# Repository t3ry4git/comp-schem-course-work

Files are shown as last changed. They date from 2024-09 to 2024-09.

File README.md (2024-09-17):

# Курсова робота з дисципліни "Комп'ютерна схемотехніка"

## Загальне завдання

Розробити обчислювальну систему з мікропрограмним управлінням (за варiантом).

## Варіант №23

1. Ємнiсть оперативноi пам'ятi (ОЗП) - 32К(надо 8 штуки в ряду, 1 ряд);
2. Елементна база ОЗП - К541РУ2(1Кх4, кол. А - 10);
3. Ємнiсть постiйного запам'ятовувального пристрою (ПЗП) - 16К(надо 4 штуки в ряду, 2 ряда);
4. Елементна база ПЗП - К555РЕ4(2Кх8, кол. А - 11);
5. Розряднiсть основноi пам'ятi (ОЗП i ПЗП) та процесора - 32;
6. Елементна база блока обробки даних - К1804ВС1;
7. Наявнiсть схеми прискореного переносу: п - передбачається.
8. Елементна база ФАМ - К1804ВУ4;
9. Елементна база мiкропрограмної пам'ятi - К541РТ2;
10. Кiлькiсть зовнiшнiх пристроїв - 16;
11. Спосiб з'єднання мiкросхем прiоритетних векторних переривань - послідовний;
12. Елементна база контролера ПДП -  К1804ВУ6;
13. Обов'язковий тип даних: 3 - char;
14. Команда для детальної розробки: 2 - дiлення цілих двійкових чисел зі знаком (співмножники та результат - у доповняльному коді), - цілочисельне ділення: ділене, дільник, частка (зі знаком), остача (без знаку).
15. Принципова схема: 1 - БПП + БМУ.

## Оцінювання 
Робота: 80

Захист: відсутній

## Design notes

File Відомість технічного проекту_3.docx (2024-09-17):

Фор-мат | | Зона | | Поз. | Позначення | | | Найменування | | | | Кільк. | Прим.
| | | | | | | | Документація загальна
| | | | | | | | Новорозроблена
А4 | | | | | ІАЛЦ.467400.003 ПЗ | | | Обчислювальна система | | | | 39
| | | | | | | | з мікропрограмним
| | | | | | | | управлінням.
| | | | | | | | Пояснювальна записка
А1 | | | | | ІАЛЦ.467400.004 Е1 | | | Обчислювальна система | | | | 1
| | | | | | | | з мікропрограмним
| | | | | | | | управлінням.
| | | | | | | | Схема електрична
| | | | | | | | структурна
А2 | | | | | ІАЛЦ.467400.005 Е2 | | | Основна пам’ять. Схема | | | | 1
| | | | | | | | електрична
| | | | | | | | функціональна
А1 | | | | | ІАЛЦ.467400.006 E3 | | | БПП та БМУ. Схема | | | | 1
| | | | | | | | електрична принципова
А4 | | | | | ІАЛЦ.467400.007 ПЕ | | | БПП та БМУ. | | | | 1
| | | | | | | | Перелік елементів
| | | | | | | ІАЛЦ.467400.002 ТП
Зм. | Арк | | № докум | | Підпис | Дата
Розроб. | | | Терентьєв І.Д. | | | | Обчислювальна система з мікропрограмним управлінням. Відомість технічного проекту | | Літ. | | | Арк. | | Арк-ів
Перевір. | | | Клятченко Я.М. | | | | | | К | - | - | 1 | | 1
| | | | | | | | | КПІ ім. Ігоря Сікорського, ФПМ гр. КВ – 11
Н. контр.
Затв. | | | Клятченко Я.М.

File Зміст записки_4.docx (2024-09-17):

##### ЗМІСТ

ПЕРЕЛІК УМОВНИХ СКОРОЧЕНЬ 2

ВСТУП 3

РОЗДІЛ 1. Структура обчислювальної системи з мікропрограмним

управлінням 8

РОЗДІЛ 2. Основна пам’ять обчислювальної системи 22

РОЗДІЛ 3. Особливості побудови блока мікропрограмного управління та

блока пріоритетних переривань 24

РОЗДІЛ 4. Формати даних 26

РОЗДІЛ 5. Формати команд 27

РОЗДІЛ 6. Команди для детальної розробки 34

СПИСОК ВИКОРИСТАНИХ ДЖЕРЕЛ 39

ДОДАТКИ
| | | | | ІАЛЦ.467400.003 ПЗ
Зм. | Арк | № докум | Підпис | Дата
Розроб. | | Терентьєв І.Д. | | | Обчислювальна система з мікропрограмним управлінням. Пояснювальна записка | Літ. | | | Арк. | Арк-ів
Перев. | | Клятченко Я.М. | | | | К | - | - | 1 | 45
| | | | | | КПІ ім. Ігоря Сікорського, ФПМ, гр. КВ – 11
Н. контр.
Затв. | | Клятченко Я.М.

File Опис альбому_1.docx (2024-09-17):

Фор-мат | | Зона | | Поз. | Позначення | | | Найменування | | | | Кільк. | Прим.
| | | | | | | | Документація загальна
| | | | | | | | Новорозроблена
А4 | | | | | ІАЛЦ.467400.001 ТЗ | | | Обчислювальна система з | | | | 2
| | | | | | | | мікропрограмним
| | | | | | | | управлінням.
| | | | | | | | Технічне завдання
А4 | | | | | ІАЛЦ.467400.002 ТП | | | Обчислювальна система з | | | | 1
| | | | | | | | мікропрограмним
| | | | | | | | управлінням.
| | | | | | | | Відомість технічного
| | | | | | | | проекту
А4 | | | | | ІАЛЦ.467400.003 ПЗ | | | Обчислювальна система з | | | | 39
| | | | | | | | мікропрограмним
| | | | | | | | управлінням.
| | | | | | | | Пояснювальна записка
А1 | | | | | ІАЛЦ.467400.004 Е1 | | | Обчислювальна система з | | | | 1
| | | | | | | | мікропрограмним
| | | | | | | | управлінням.
| | | | | | | | Схема електрична
| | | | | | | | структурна
А2 | | | | | ІАЛЦ.467400.005 Е2 | | | Основна пам’ять. Схема | | | | 1
| | | | | | | | електрична
| | | | | | | | функціональна
А1 | | | | | ІАЛЦ.467400.006 E3 | | | БПП та БМУ. Схема | | | | 1
| | | | | | | | електрична принципова
А4 | | | | | ІАЛЦ.467400.007 ПЕ | | | БПП та БМУ. | | | | 1
| | | | | | | | Перелік елементів
| | | | | | | ІАЛЦ.467400.000 ОА
Зм. | Арк | | № докум | | Підпис | Дата
Розроб. | | | Терентьєв І.Д. | | | | Обчислювальна система з мікропрограмним управлінням Опис альбому | | Літ. | | | Арк. | | Арк-ів
Перевір. | | | Клятченко Я.М. | | | | | | К | - | - | 1 | | 1
| | | | | | | | | КПІ ім. Ігоря Сікорського, ФПМ гр. КВ – 11
Н. контр.
Затв. | | | Клятченко Я.М.

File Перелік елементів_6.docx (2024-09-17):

Позначення | | | Найменування | | | | Кільк. | | | | Прим.
| | | Конденсатори
С1 | | | К10-17-1аН90-0,068 мкФ ОЖО 460.043.ТУ | | | | 1
С2..С42 | | | К53-1А-16В-15 мкФ ОЖО 464.056 ТУ | | | | 41
| | | Мікросхеми
DD1 | | | K1804ВУ4 бК0.348.620-04 ТУ | | | | 1
DD2.1 | | | К555ЛЛ3 бК0.348.289-04 ТУ | | | | 1
DD3.1, DD3.2 | | | К555ЛА3 бК0.348.289-01 ТУ | | | | 1
DD4 | | | КР1533КП15 бК0.348.806-06 ТУ | | | | 1
DD5-DD26 | | | К541РТ2 бК0.348.546-03ТУ | | | | 22
DD27-DD37 | | | К580ИР82 бК0.348.745-15 ТУ | | | | 11
DD38, DD39 | | | К1804ВН1 бК0.348.620-06 ТУ | | | | 2
DD40 | | | К1804ВР3 бК0.348.620-06 ТУ | | | | 1
DD41,DD42 | | | К541РТ2 бК0.348.546-03ТУ | | | | 2
| | | Резистори
R1 | | | МЛТ-0,125-1кОМ+-10% | | | | 1
| | | | | | ІАЛЦ.467400.007 ПЕ
Зм. | Арк | № докум | | Підпис | Дата
Розроб. | | Терентьєв І.Д. | | | | БПП та БМУ. Перелік елементів | | Літ. | | | | Арк. | Арк-ів
Перев. | | Клятченко Я.М. | | | | | | К | - | - | | 1 | 1
| | | | | | | | КПІ ім. Ігоря Сікорського, ФПМ гр. КВ – 11
Н. контр.
Затв. | | Клятченко Я.М.

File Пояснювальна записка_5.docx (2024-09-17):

# ПЕРЕЛІК УМОВНИХ СКОРОЧЕНЬ

АЛП – арифметико-логічний пристрій

БМУ – блок мікропрограмного управління

БОД – блок обробки даних

БПП – блок пріоритетних переривань

ВП – віртуальний процесор

ВІС – велика інтегральна схема

ЕОМ – електронна обчислювальна машина

ІМС – інтегральна мікросхема

КС – контролер станів

КМП – контролер послідовності мікрокоманд

КПДП – контролер прямого доступу до пам’яті

МП – мікропроцесор

МС – мікросхема

МПК – мікропроцесорний комплект

МПП – мікропрограмна пам’ять

МПС – мікропроцесорна секція

ОС – обчислювальна система

ОЗП – оперативний запам’ятовувальний пристрій

ПВВ – пристрій вводу/виводу

ПЗП – постійний запам’ятовувальний пристрій

РЗП – регістровий запам’ятовувальний пристрій

СМУ – схема мікро програмного управління

СПП – схема прискореного переносу

СУСЗ – схема управління станами і зсувами

ТТЛ – транзисторно-транзисторна логіка

ФАМ – формувач адрес мікрокоманд

ЦПЕ – центральний процесорний елемент

# ВСТУП

Обчислювальна техніка відіграє ключову роль у науково-технічному прогресі. Використання цифрових обчислювальних пристроїв дозволяє створювати на їх основі контрольні та керуючі системи, які інтегруються у прилади, машини, технологічні установки та процеси. Це сприяє значному підвищенню рівня автоматизації, економії енергії, сировини та матеріалів, а також покращенню продуктивності та якості праці.

Одним з важливих досягнень мікроелектроніки та обчислювальної техніки є розробка мікропроцесорів (МП). Використання мікропроцесорів у промисловому обладнанні дозволяє значно знизити їх вартість у порівнянні з системами на основі малих та середніх інтегральних схем, які виконують аналогічні функції. Одночасно з цим досягається суттєве зменшення маси, габаритів та енергоспоживання системи. Перехід на нову елементну базу підвищує технологічність систем промислової автоматики та значно розширює економічно доступну сферу їх застосування.

Промисловість освоїла та серійно випускає велику кількість мікропроцесорних комплектів великих інтегральних схем (ВІС) різної архітектури. Розвиток елементної бази мікропроцесорів здійснюється за кількома взаємодоповнюючими напрямками, що дозволяє гнучко адаптувати архітектуру систем управління до вимог конкретних застосувань та умов експлуатації. Останніми роками чітко простежується тенденція стандартизації систем команд та інтерфейсів електронно-обчислювальних машин (ЕОМ) та мікроконтролерів, що забезпечує взаємозамінність комп’ютерів та сумісність їхнього програмного забезпечення.

Мікропроцесор (МП) – це пристрій, який обробляє інформацію відповідно до програми, поданої командами на його входи, і реалізований в одній або кількох великих інтегральних схемах (ВІС). Очевидно, що МП не може функціонувати без інших інтегральних мікросхем (ІМС), які виконують функції синхронізації, узгодження по навантаженню тощо.

Набір інтегральних схем, сумісних за конструктивно-технологічними характеристиками та призначених для створення мікропроцесорів, ЕОМ і мікропроцесорних систем, називається мікропроцесорним комплектом (МПК). МПК включає ВІС процесора, ВІС регістрів, ІМС регістрів, інтерфейсів пристроїв введення-виведення, ВІС контролерів, генераторів, таймерів тощо. Таким чином, мікропроцесор виконує арифметичні та логічні операції, аналізує та приймає рішення, які змінюють процес обчислень, керує процесом введення та виведення інформації, тобто виконує функції центрального процесора ЕОМ.

Для однокристальних 8-розрядних мікропроцесорів характерне використання регістрової та квазі-регістрової адресації, яка дозволяє в межах 8-розрядної команди задавати операції класу "регістр-регістр" або "регістр-пам'ять", що відповідає вимогам обробки програм керування. Однокристальні мікропроцесори мають фіксовану систему команд, не допускають розширення і мають універсальне призначення.

Секційні мікропроцесори мають довільну систему команд (реалізовану методом емуляції), допускають розширення, володіють вищою швидкодією та використовуються для створення специфічних інтегральних схем. При використанні секційних мікропроцесорів процесор ЕОМ будується на основі набору ВІС центральних процесорних елементів з блоком прискореного переносу, які утворюють операційну частину, та блоку мікропрограмного управління, який утворює пристрій керування.

Для реалізації інтерфейсу в склад секційних комплектів включаються ВІС магістральних приймачів-передавачів, контролерів переривань і контролерів інтерфейсів, а для генерації синхронізуючих імпульсів процесора – контролерів синхронізації. Важливо розрізняти контролери та процесори команд, оскільки вони відрізняються кількістю рівнів управління. Мікроконтролери мають один рівень управління процесом обробки інформації – рівень мікрокоманд. Процесори команд мають два рівня управління процесом обробки інформації:

1. Рівень команд.
2. Рівень мікрокоманд.

Таким чином, процесори команд можуть виконувати практично довільну множину команд, маючи обмежену кількість мікрокоманд. Прикладний алгоритм зберігається у зовнішній пам’яті, тоді як в мікропрограмній пам’яті зберігаються мікропрограми емуляції команд. Замість виконання команди, виконується мікропрограма її емуляції.

Емуляція має такі переваги:

- спрощення структури мікропроцесора;
- можливість роботи з практично будь-якою системою команд;
- полегшення розробки мікропроцесора;
- можливе збільшення швидкодії завдяки використанню внутрішньої пам’яті.

Розроблювана мікроЕОМ призначена для реалізації системи команд. Вона створюється в навчальних цілях, щоб навчити проектувати системи обробки даних.

Мікропроцесорний комплект на основі однокристального процесора являє собою одну мікросхему, тоді як на основі секційного – кілька мікросхем, кожна з яких є мікропроцесорною секцією.

Структурно мікропроцесорна секція складається з таких частин:

- блок внутрішньої пам’яті;
- арифметико-логічний пристрій;
- блок регістра Q;
- блок управління.

До секційних мікропроцесорних комплектів належить набір високошвидкісних великих інтегральних схем (ВІС) серії К1804, призначений для створення швидкодіючих мікропроцесорних пристроїв з розрядно-модульною організацією (ЕОМ середньої продуктивності, контролерів, засобів цифрової автоматики). Цей комплект призначений для реалізації структур машин з довільною системою команд. Секційна архітектура ВІС комплекту дозволяє нарощувати розрядність пристроїв, а управління здійснюється мікропрограмним способом. Орієнтація на обрану систему команд реалізується шляхом емуляції на мікропрограмному рівні, записуючи необхідні мікропрограми у постійний запам'ятовувальний пристрій. До серії К1804 входять наступні ВІС:

- Два типи мікропроцесорних секцій: К1804ВС1 та К1804ВС2.
- Два типи секційних блоків мікропрограмного управління: К1804ВУ1 і К1804ВУ2.
- Контролер послідовностей мікрокоманд: К1804ВУ3.
- Блок мікропрограмного управління: К1804ВУ4.
- Секційний контролер адреси: К1804ВУ5.
- Паралельний регістр: К1804ИР1.
- Блок прискореного переносу: К1804ВР1.
- Контролер станів: К1804ВР2.
- Три типи секційних магістральних приймачів-передавачів: К1804ВА1, К1804ВА2, К1804ВА3.
- Генератор синхронізації: К1804ГГ1.
- Багатоцільовий буферний регістр: К1804ИР2.
- Секційний порт вводу/виводу: К1804ИР3.

Усі ВІС працюють при напрузі живлення 5В ±0.25В та сумісні зі стандартними ТТЛ схемами.

У курсовому проекті буде реалізовано процесор команд. Керуюча частина МП (Рис. 1.1) побудована на основі принципу мікропрограмного управління.

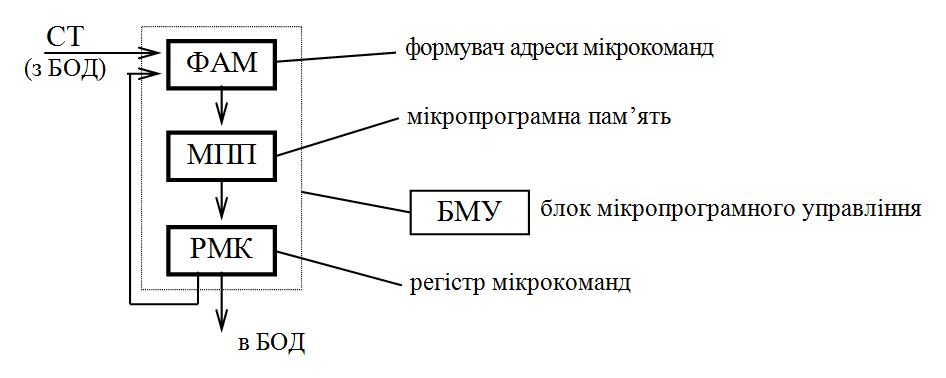
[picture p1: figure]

Рис. 1.1 Структура керуючої частини МП

Мікропрограма управління процесом або об’єктом знаходиться у мікропрограмній пам'яті (МПП). Формувач адрес мікрокоманд (ФАМ) генерує адреси мікрокоманд. У кожному такті поточна мікрокоманда зберігається в регістрі мікрокоманд. У наступних розділах буде проведений детальний опис блоків, що проектуються за варіантом курсового проекту.

# РОЗДІЛ 1. СТРУКТУРА ОБЧИСЛЮВАЛЬНОЇ СИСТЕМИ З МІКРОПРОГРАМНИМ УПРАВЛІННЯМ

До складу обчислювальної системи з мікропрограмним управлінням входять наступні компоненти:

- блок обробки даних;
- блок мікропрограмного управління;
- блок пріоритетних переривань;
- пам’ять;
- зовнішні пристрої;
- контролер прямого доступу до пам’яті.

Характеристика блоку обробки даних:

До складу блоку обробки даних (БОД) входять арифметико-логічний пристрій (АЛП) та схема управління станом і зсувами (СУСЗ). АЛП забезпечує виконання арифметичних та логічних операцій і будується на основі мікропроцесорних секцій (МПС), кожна з яких обробляє дані в 4 розряди. Структурна схема МПС включає чотири блоки: блок внутрішньої пам'яті, блок операційного автомата (ОА), блок регістра Q та блок управління. Обчислювальна система є 32-розрядною, тому АЛП складається з восьми МПС К1804ВС1.

Мікросхеми К1804ВС1 мають наступні виводи (див. рис. 1.2 та рис. 1.3):

- MI (9 розрядів) – визначає, яку саме мікрооперацію виконуватиме операційний автомат у поточному циклі;
- A, B (по 4 розряди) – адресні входи, дані надходять з регістрів A і B відповідно;
- D (4 розряди) – вхід з шини даних;
- Y (4 розряди) – вихід на шину Y;
- OE – вхід для сигналу дозволу видачі результату на шину Y;
- C4 – перенос за межі старшого розряду результату;
- F3 – значення (копія) старшого розряду результату (знак результату);
- Z – ознака нульового результату;
- OVR – переповнення результату;
- P – сигнал поширення переносу;
- G – сигнал генерації переносу;
- CI – вхідний перенос (перенос у нульовий розряд);
- PQ3 – вивід зсуву старшого розряду регістра Q;
- PQ0 – вивід зсуву молодшого розряду регістра Q;
- PF0 - PF3 – виводи, які залежно від напряму зсуву є входом або виходом, через які здійснюється запис значення в розряд, що звільняється, і видача вмісту розряду, що виштовхується.

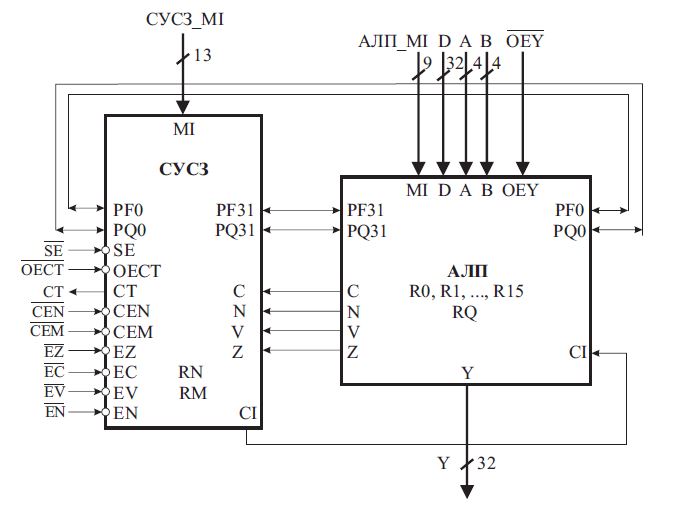
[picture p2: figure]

Рис. 1.2 Узагальнена структура блока обробки даних

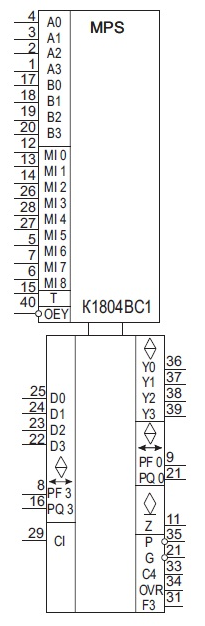
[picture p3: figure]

Рис. 1.3 Умовне графічне позначення схеми МПС К1804ВС1 на принципових схемах

Схема управління станами і зсувами (мікросхема К1804ВР2) призначена для наступних завдань:

- Формування сигналу вхідного переносу (СІ) для молодшої МПС АЛП та СПП.
- Забезпечення арифметичних, логічних, циклічних та інших зсувів даних в АЛП.
- Виконання мікрооперацій над бітами слова стану (C4, F3, Z, OVR).
- Формування сигналу умови (CondiTion).

Призначення виводів мікросхеми К1804ВР2 (див. рис. 1.4):

- МI0 – МI12 – входи для мікроінструкцій.
- C, N, V, Z – входи слова стану.
- YC, YN, YV, YZ – входи двонаправленої шини Y для запису слова стану у зовнішній регістр та читання з регістра.
- OEY – дозвіл на видачу слова стану на шину Y.
- CEN, CEM – дозвіл запису в регістри N і M відповідно.
- EZ, EN, EV, EC – входи керування записом в окремі розряди регістру M.
- CT – вихід сигналу умови (тристабільний).
- OECT – дозвіл видачі сигналу умови CT на шину.
- PF3, PF0, PQ3, PQ0 – входи/виходи для організації зсувів.
- SE – сигнал дозволу зсуву.

Після виконання кожної мікрооперації формується слово стану, яке складається з наступних ознак результату:

- C4 – перенос за межі старшого розряду результату.
- F3 – значення (копія) старшого розряду результату (знак результату).
- Z – ознака нульового результату (вихід з відкритим колектором).
- OVR – ознака переповнення результату.

Після виконання кожної мікрооперації в АЛП зі старшої МПС в СУСЗ надходять ознаки результату C4, F3, OVR, Z, де над ними можуть виконуватись різноманітні операції. Поточні або попередні значення слова стану можуть зберігатись у двох внутрішніх регістрах (RgN, RgM) або у зовнішньому стеку. На підставі слова стану формується сигнал умови СТ, який надходить в блок мікропрограмного управління й використовується для організації умовних переходів в мікропрограмах.

Два можливих способи об’єднання мікропроцесорних секцій в АЛП:

1. З послідовним переносом із секції в секцію.
2. З паралельним переносом.

У даній роботі використовується спосіб об’єднання схем з паралельним переносом із секції в секцію. В такому випадку для об’єднання мікропроцесорних секцій використовується схема прискореного переносу (див. Рис. 1.5).

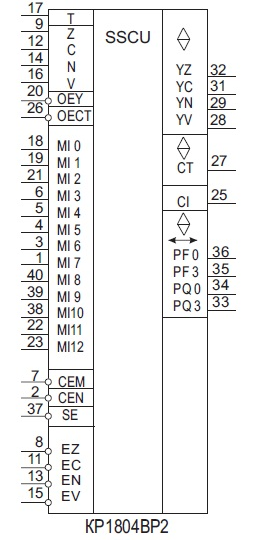
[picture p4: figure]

Рис. 1.4 Умовне графічне позначення схеми СУСЗ К1804ВР2 на принципових схемах

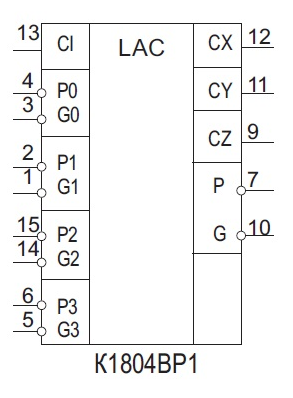
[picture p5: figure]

Рис. 1.5 Умовне графічне позначення схеми прискореного переносу К1804ВР1 на принципових схемах

Обов'язкові компоненти блоку мікропрограмного управління (БМУ, Рис. 1.6):

1. ФАМ (формувач адреси мікрокоманд):
- Використовується спеціальна мікросхема К1804ВУ4.
- Генерує 12-розрядні адреси мікрокоманд.
- Виконує 16 мікроінструкцій, включаючи отримання наступної адреси, повторення адреси, умовні та безумовні переходи, виклики мікропідпрограм та організацію циклів.
- Виводи:
  - D0 – D11: шина адреси наступної команди.
  - RLD: дозвіл запису до регістру адреси/лічильника циклу.
  - CI: вхідний перенос лічильника мікрокоманд.
  - FL: ознака переповнення внутрішнього стеку (глибина стеку – п'ять 12-розрядних мікрокоманд).
  - A0 – A11: шина адреси мікрокоманди.
  - CC: код умови.
  - CCE: код дозволу умови.
- Функції: формує адресу мікрокоманди, використовується для організації мікропрограм.
2. ПМК (пам'ять мікрокоманд):
  - Зберігає мікропрограму емуляції мікрокоманд та мікропрограми обслуговування зовнішніх пристроїв.
3. РМК (регістр мікрокоманд):
  - Зберігає поточну мікрокоманду, що виконується.
4. МУ (мультиплексор умови):
  - Використовується для вибору умови для організації умовних переходів.
5. ІНВ (інвертор умови):
  - Являє собою суматор за модулем 2, необхідний для виконання умовних переходів.

Допоміжні компоненти:

  - ППА (перетворювач початкової адреси): перетворює код операції мікрокоманди в початкову адресу мікропрограми.
  - ПА (перетворювач адреси): трансформує вектор переривання в початкову адресу мікропрограми обслуговування даного переривання.

Мікросхема К1804ВУ4 формує 3 сигнали управління:

- RE: дозвіл РМК.
- ME: дозвіл перетворення початкової адреси (ППА).
- VE: дозвіл перетворення адреси.

Ці компоненти забезпечують основні функції для керування мікропрограмами та взаємодії з зовнішніми пристроями в обчислювальній системі з мікропрограмним управлінням.

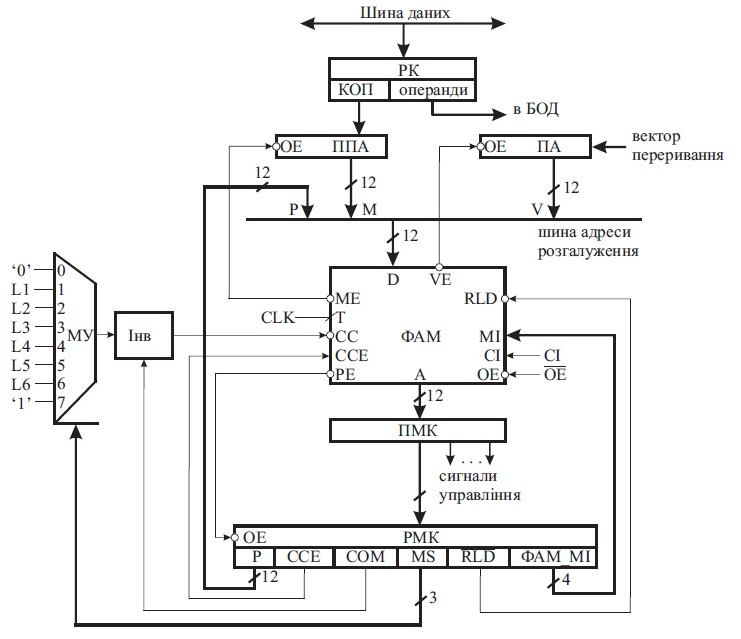
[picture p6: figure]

Рис. 1.6 Структура блока мікропрограмного управління

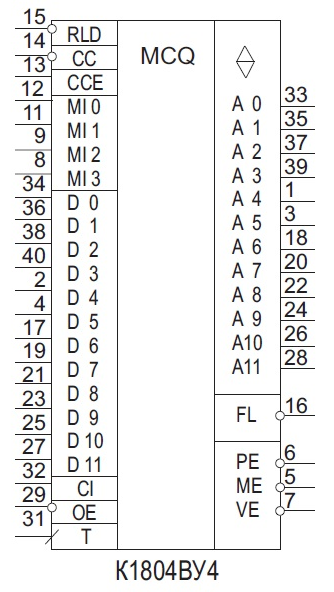
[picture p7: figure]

Рис. 1.7 Умовне графічне позначення мікросхеми формувача адрес мікрокоманд К1804ВУ4 на принципових схемах

Мікросхема К1804ВН1 призначена для прийому та обслуговування запитів на переривання від 8 зовнішніх пристроїв. Вона формує вектор переривання і має наступні виводи:

- INR0 – INR7: входи запитів на переривання.
- ER: визначає форму сигналів запитів.
- MK0 – MK7: шина маски.
- S0 – S2: шина стану.
- MI0 – MI3: входи мікроінструкцій.
- EI: дозвіл виконання мікроінструкцій.
- OVR: сигнал переповнення.
- VEC0 – VEC2: вектор переривання.

Чотири розряди коду мікроінструкції MI0–MI3 дозволяють створити систему команд БПП з 16 команд:

- RESET IR: очистка регістра запитів.
- CLR IR, val: очистка окремих розрядів регістра запитів за значеннями з шини маски.
- CLR IR, MR: очистка окремих розрядів регістра запитів за значеннями з регістра маски.
- CLR IR, VR: очистка одного з розрядів регістра запитів під управлінням вектора запиту.
- LOAD MR, val: завантаження регістра маски значеннями val.
- READ MR: читання регістра маски.
- CLR MR, val: очистка регістра маски за значеннями з шини маски.
- SET MR, val: встановлення в «1» окремих розрядів регістра маски за значеннями з шини маски.
- SET MR: встановлення в «1» всіх розрядів регістра маски.
- RESET MR: очистка регістра маски.
- LOAD SR, val: завантаження регістра стану значеннями val.
- READ SR: читання слова стану.
- READ VR: читання вектора переривань.
- EI: дозвіл переривань.
- DI: заборона переривань (виходу з регістра запитів IR).
- RESET: загальна очистка схеми.

Мікросхема К1804ВРЗ дозволяє об’єднати до 8 мікросхем К1804ВН1 для створення блоку пріоритетних переривань (БПП) з кількістю ліній переривань до 64. Вона має наступні виводи:

- INR0 – INR7: входи запитів на переривання.
- ER: визначає форму сигналів запитів.
- MK0 – MK7: шина маски.
- S0 – S2: шина стану.
- MI0 – MI3: входи мікроінструкцій.
- EI: дозвіл виконання мікроінструкцій.
- OVR: сигнал переповнення.
- VEC0 – VEC2: вектор переривання.

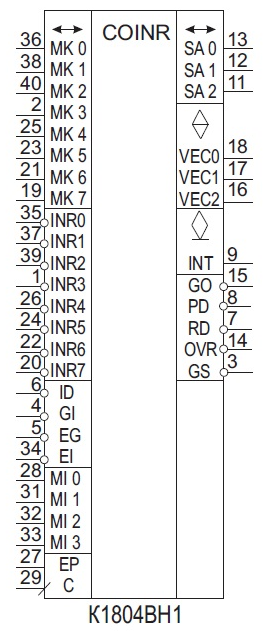
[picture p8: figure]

Рис. 1.8 Умовне графічне позначення мікросхеми векторних переривань K1804BH1 на принципових схемах

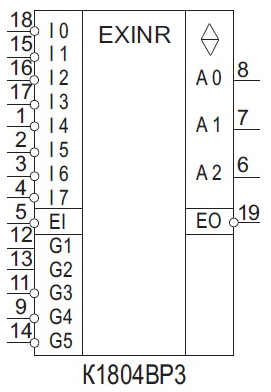
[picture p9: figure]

Рис. 1.9 Умовне графічне позначення мікросхеми розширювача векторних переривань K1804BР3 на принципових схемах

Прямий доступ до пам’яті (ПДП) – спосіб вводу/виводу інформації, під час якого встановлюється безпосередній зв’язок між приладами вводу/виводу (ПВВ) і пам’яттю, а передача даних виконується без участі центрального процесору. Досягається висока швидкодія обміну інформацією, звільнення центрального процесору від безпосередньої передачі даних. Для організації ПДП використовують контролер ПДП (КПДП).

Функції КПДП:

- керування режимами передачі;
- генерація адреси;
- пересилка даних;
- підрахунок кількості слів.

Основною структурною одиницею КПДП є генератор адреси (ГА) К1804ВУ6.

Функції мікросхеми К1804ВУ6:

- формування послідовних адрес комірок пам’яті під час передачі даних до пам’яті або з пам’яті;
- підрахунок кількості слів;
- формування сигналу кінця передачі.

Для встановлення зв’язку між ПВВ і пам’яттю використовують механізм пріоритетних переривань. БПП приймає запит на переривання від ПВВ, формує сигнал IR – вимога переривання і вектор переривання ПА трансформує вектор переривання в 12-розрядну початкову адресу мікропрограми обслуговування ПВВ, яка знаходиться в МПП. Ця програма налаштовує ГА на потрібний режим роботи, задає кількість слів, початкову або кінцеву адресу пам’яті та ініціює початок передачі інформації. Дані з ПВВ передаються через внутрішню три-стабільну шину на шину даних пам’яті (через приймально-передавальний пристрій), а адресу формує ГА.

Система команд ГА:

- 000 WRCR – запис в регістр управління
- 001 RDCR – читання з регістра управління
- 101 LDAD – завантаження регістра та лічильника адреси
- 110 LDWC – завантаження регістра кількості слів та лічильника слів
- 011 RDAC – читання лічильника слів
- 010 RDWC – читання лічильника слів
- 100 REIN – завантаження лічильників з регістрів
- 111 ENCT – запуск (дозвіл лічби)

Режими роботи К1804ВУ6:

- Режим 0: До появи ’0’ у лічильнику слів

До регістру керування заноситься 100, до регістру кількості слів і лічильника слів – кількість слів, до регістру і лічильника адреси – кінцева адреса та відбувається зменшення значень лічильників на 1 на кожному кроці до появи у лічильнику слів ’0’.

- Режим 1: Передача до заданої кількості слів

До регістру управління заноситься 001, до регістру кількості слів – кількість слів, до лічильника слів – 0, до регістру і лічильника адреси – початкова адреса та відбувається збільшення значень лічильників на 1 на кожному кроці до появи рівності регістру та лічильника слів.

- Режим 2: Передача до заданої адреси

В цьому режимі виконується передача до заданої адреси, причому лічильник слів виконує функції регістра. Операція пересилки зупиняється, коли вміст лічильника адреси дорівнює вмісту лічильника слів. До регістру управління заноситься 010, до регістру слів – кінцева адреса, до лічильника адреси – початкова адреса та відбувається збільшення значення лічильника адреси на 1 при кожному кроці до появи рівності лічильника слів та адреси.

- Режим 3: Передача до переповнення лічильника слів

До лічильника слів записується доповнення кількості слів, які необхідно передати. Лічильник слів виконує інкремент до переповнення (сигнал WCO). До регістру управління заноситься 011, до лічильника і регістра слів – кількість слів в доповняльному коді, до лічильника і регістра адреси – початкова адреса.

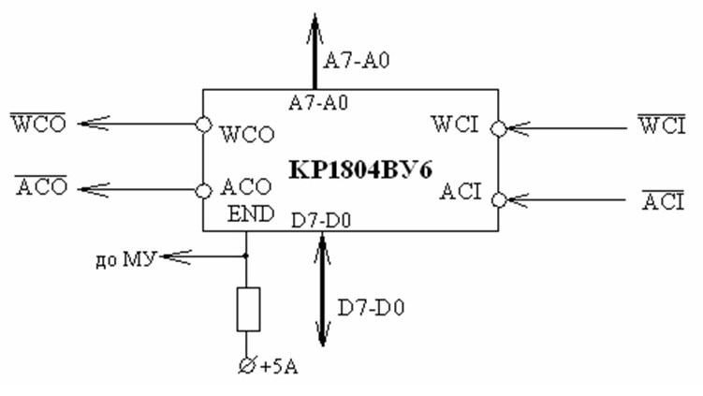
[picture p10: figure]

Рис. 1.10 Умовне графічне позначення контролера прямого доступу до пам’яті К1804ВУ6

# РОЗДІЛ 2. ОСНОВНА ПАМ’ЯТЬ ОБЧИСЛЮВАЛЬНОЇ СИСТЕМИ

Розробка функціональної схеми основної пам'яті ЕОМ включає в себе кілька ключових етапів. По-перше, потрібно визначити потрібну ємність оперативної та постійної пам'яті відповідно до вимог системи. Далі необхідно визначити кількість субмодулів мікросхем пам'яті, які потрібні для досягнення необхідної розрядності шини даних. Важливо також розподілити адресний простір між оперативною та постійною пам'яттю, враховуючи потреби системи.

Необхідно спроектувати функціональну схему основної пам’яті ЕОМ ємністю 50 Кбайт.

Основна пам’ять складається з:

- ОЗП, ємністю 32 Кб;
- ПЗП, ємністю 16 Kб.
- Елементна база ОЗП: К541РУ2.
- Елементна база ПЗП: К555РЕ4.

К541РУ2. Мікросхема має 10 адресних входів, а також 4-розрядну двонапрямну тристабільну шину для вводу/виводу інформації і дозволяє зберігати 1Кх4 біт інформації.

Керуючі сигнали:

- CS – вибір мікросхеми;
- ОЕ – дозвіл видачі даних на шину;
- W/R – запис/читання.

К555РЕ4. Мікросхема має 11 адресних входів та 8-розрядну шину виводу і дозволяє зберігати 2Кх8 біт інформації.

Керуючі сигнали:

- CS3, CS2, CS1 – для вибору мікросхеми.

Оскільки мінімальна одиниця інформації, що адресується – 32-розрядне слово, то ємність основної пам’яті складає 10K 32-розрядних слів.

- ОЗП – 8К 32-розрядних слів.
- ПЗП – 2К 32-розрядних слів.

Розрядність шини адрес для пам’яті:

- ОП = ]10K[ = ]log10[ + 10 = 14

Для досягнення необхідної розрядності МС пам’яті об’єднуються в субмодулі. Кількість мікросхем ОЗП у субмодулі – 8, ПЗП – 4.

Для досягнення необхідної ємності субмодулі об’єднуються в модулі. Кількість субмодулів ОЗП у модулі – 8, ПЗП – 2.

Таблиця 2.1 Розподіл адресного простору

| A14 | А13 | А12 | А11 | А10 | A9 | … | … | … | … | … | А0 | HEX
ОЗП | 0 | 0 | 0 | 0 | 0 | 0 | … | … | … | … | … | 0 | 0000h … 1FFFh
| … | … | DC | | | … | Р У 2 | | | | | …
| 0 | 0 | 1 | 1 | 1 | 1 | … | … | … | … | … | 1
ПЗП | 0 | 1 | 0 | 0 | 0 | 0 | … | … | … | … | … | 0 | 2000h … 7FFFh
| … | DC | | | … | Р Е 4 | | | | | | …
| 1 | 1 | 1 | 1 | 1 | 1 | … | … | … | … | … | 1

Розряд А14 використовується для вибору ОЗП або ПЗП.

Розряди А9 – А0 подаються на мікросхеми оперативної пам’яті.

Розряди А10 – А0 подаються на мікросхеми постійної пам’яті.

Розряди А12 – А10 подаються на дешифратор ОЗП для вибору субмодулів оперативної пам’яті.

Розряди А13 – А11 подаються на дешифратор ПЗП для вибору субмодулів постійної пам’яті.

# РОЗДІЛ 3. ОСОБЛИВОСТІ ПОБУДОВИ БЛОКА МІКРОПРОГРАМНОГО УПРАВЛІННЯ ТА БЛОКА ПРІОРИТЕТНИХ ПЕРЕРИВАНЬ

Блок мікропрограмного управління:

Основний елемент блока мікропрограмного управління ФАМ побудований на основі елементної бази мікросхеми К1804ВУ4 (DD1). Сигнал СС потрапляє в ФАМ з інвертора умови (DD2.1), який реалізовано на мікросхемі К555ЛЛ3. На інвертор умови подається сигнал СОМ (РМК6) і сигнал з мультиплексора умови. Мультиплексор умови (DD4) реалізовано на мікросхемах КР1533КП15. МПП складається з двох субмодулів мікросхем КР556РТ7 (DD5 – DD15 та DD16 – DD26). Вибір субмодуля відбувається по сигналу ФАМ OE та старшому розряду адреси А11 (DD3.1 використовується для інвертування сигналу А11, щоб вибрати перший субмодуль МПП). Субмодулі складаються з 11 мікросхем кожен та забезпечують необхідну розрядність МПП (84 розряди). Виходи 1 – 84 МПП подаються на РМК – регістр мікрокоманд, який реалізовано на основі елементної бази мікросхем К580ИР82 (DD27 – DD37).

Блок пріоритетних переривань:

Обчислювальна система з мікропрограмним управлінням розрахована на 16 зовнішніх пристроїв, тому БПП складається з двох схем векторних переривань К1804ВН1 (DD38, DD39).

Розширювач векторних переривань (РВП) використовується для об’єднання декількох схем векторних переривань, щоб таким чином можна було під’єднати до обчислювальної системи більшу кількість зовнішніх пристроїв. Можливі два способи об’єднання схем векторних переривань: послідовний та паралельний. За варіантом реалізовано послідовне підключення.

РВП реалізовано на МС К1804ВР3 (DD40). На входи І РВП під’єднуються виходи GS СВП, на входи G подається мікроінструкція, вхід ЕІ відповідає за дозвіл запису. На виході А0 матимемо останній розряд адреси вектора переривання VEC. Даний сигнал подаємо на ПА, реалізований на двох мікросхемах КР556РТ7 (DD41, DD42), який генерує адресу мікропрограми обробки даного переривання та подає її на вхід ФАМ.

# РОЗДІЛ 4. ФОРМАТИ ДАНИХ

32-розрядна обчислювальна система з мікропрограмним управлінням оперує з такими форматами даних:

1.  Цілі 8-бітні числа без знаку (формат CHAR)

7 0

Діапазон: 0… 2⁸-1

2.  Цілі 32-бітні числа без знаку (формат INT)

31 0

Діапазон: 0...2³²- 1

3.  Цілі 32-бітні числа зі знаком (формат INTG)

31 30 0

знак

Діапазон: -2³¹…2³¹-1

4.  Числа з плаваючою крапкою (формат REAL)

31 30 23 22 0

знак | характеристика числа | мантиса числа

Діапазон: 1.17549×10⁻³⁸ … 3.402823×10³⁸

5. Десяткові числа (формат BCD)

31 0

Діапазон: 0 … 99 999 999

# РОЗДІЛ 5. ПРОЕКТУВАННЯ СИСТЕМИ КОМАНД

## 5.1 Емуляція команд

ЕОМ здійснює емуляцію системи команд віртуального процесора. Це означає, що кожна команда, яка реалізована в процесорі емуляції, замінюється в ЕОМ послідовністю мікрокоманд (мікропрограмою) з системи команд, реалізованої в апаратній логіці ЕОМ.

Програмістська модель віртуального процесора включає 4 компоненти:

- 10 регістрів загального призначення (REGa … REGj);
- програмний лічильник віртуального процесора (РС);
- слово стану віртуального процесора (PSW);
- покажчик стеку (SP).

Компоненти віртуального процесора розміщуються у молодших адресах віртуальної пам’яті:

Адреса | ОЗП
… … | Програма
0Ch | SP
0Bh | PSW
0Ah | Rj
09h | Ri
08h | Rh
07h | Rg
06h | Rf
05h | Re
04h | Rd
03h | Rc
02h | Rb
01h | Ra
00h | РС

Структура PSW:

15 14 12 10 8 6 4 2 0

| | | | | O | | S | | Z | | A | | P | | C

О (Overflow) –ознака переповнення;
S (Sign) – ознака від'ємного результату;
Z (Zero) – ознака нульового результату;
A (Auxiliary carry) – ознака переносу з молодшої тетради;
P (Parity) – ознака парності;
C (Carry) – ознака переносу в старший розряд.

Узагальнений алгоритм емуляції:

1.  Читання регістра програмного лічильника віртуального процесора з ОЗП в один з регістрів БОД.
2.  Формування адреси команди.
3.  Читання команди з ОЗП.
4.  Виконання команди:
- перехід на мікропрограму емуляції;
- виконання мікропрограми.
5.  Запис результату в ОЗП.
6.  Модифікація регістра слова стану:
- читання слова стану з ОЗП в регістр БОД;
- модифікація значень ознак;
- запис слова стану в ОЗП;
- модифікація програмного лічильника;
- запис нового значення лічильника в ОЗП.

## 5.2 Формати команд

- КОП (Operation Code) – код операції
- R, R1, R2 – регістри (RA … RJ)
- M – непряма адресація пам’яті (адреса комірки пам’яті у регістрі)
- addr – 16-розрядна адреса комірки пам’яті
- disp8 – зміщення (1 байт). Діапазон: -128 … 127
- #d16 – безпосередні дані
- SP – регістр покажчику стеку (Stack Pointer)
- PC – лічильник команд (Program Counter)

Двобайтні команди:

15 | 8 | 7 | 0
КОП | | —

15 | 8 | 7 | 4 | 3 | 0
КОП | | — | | R

15 | 8 | 7 | 4 | 3 | 0
КОП | | R2 | | R1

15 | 8 | 7 | 4 | 3 | 0
КОП | | M(@R) | | R

15 | 8 | 7 | 4 | 3 | 0
КОП | | — | | M(@R)

15 | 8 | 7 | | | 0
КОП | | disp8

Чотирибайтні команди:

15 8 7 4 3 0 15 0

КОП | — | R | | #d16

15 8 7 0 15 0

КОП | | | #d16

15 8 7 0 15 0

КОП | — | | addr

15 8 7 4 3 0 15 0

КОП | — | R | | addr

## 5.3 Система команд

Команди пересилки даних:

mov R,M;

mov M,R;

mov R1,R2;

mov R,#d16;

xchg R1,R2;

xchg R,M;

push R;

pop R;

Арифметичні команди:

add R1,R2; add R,M;

add M,R; add R,#d16;

adc R1,R2; adc R,M;

adc M,R; adc R,#d16;

addf R1,R2; addf R,M;

addf M,R; addf R,#d16;

addb R1,R2; inc R;

sub R1,R2; sub R,M;

sub M,R; sub R,#d16;

subc R1,R2; subc R,M;

subc M,R; subc R,#d16;

subf R1,R2; subf R,M;

subf M,R; subf R,#d16;

subb R1,R2; dec R;

neg R; mul R1,R2;

mul R,M; mul M,R;

mul R,#d16; mulf R1,R2;

mulf R,M; mulf M,R;

mulf R,#d16; div R1,R2;

div R,M; div M,R;

div R,#d16; divf R1,R2;

divf R,M; divf M,R;

divf R,#d16; sqr R;

sqrf R; pow R1,R2;

not R; and R1,R2;

or R1,R2; xor R1,R2;

nxor R1,R2; nand R1,R2;

srl R1,R2; sll R1,R2;

sra R1,R2; sla R1,R2;

src R1,R2; slc R1,R2;

Команди порівняння:

cmp R1,R2; cmp R,M

cmp R,#d16

Команди переходів:

jmp addr

ja disp8

jna disp8

jc disp8

jnc disp8

jz disp8

jnz disp8

jo disp8

jno disp8

jp disp8

jnp disp8

js disp8

jns disp8

loop disp8

call addr

ret

Інші команди:

nop – no operation

hlt – halt operation

di – disable interrupts

ei – enable interrupts

## 5.4 Програмування перетворювача початкової адреси (ППА)

№ | КОП | адреса в МПП | команда | довжина команди | формати даних
1 | 01h | 010h | mov R,M | 2 | INT,INTG,REAL,BCD,CHAR
2 | 02h | 020h | mov M,R | 2 | INT,INTG,REAL,BCD,CHAR
3 | 03h | 030h | mov R1,R2 | 2 | INT,INTG,REAL,BCD,CHAR
4 | 04h | 040h | mov R,#d16 | 4 | INT,INTG,REAL,BCD,CHAR
5 | 05h | 050h | xchg R1,R2 | 2 | INT,INTG,REAL,BCD,CHAR
6 | 06h | 060h | xchg R,M | 2 | INT,INTG,REAL,BCD,CHAR
7 | 07h | 070h | push R | 2 | INT,INTG,REAL,BCD,CHAR
8 | 08h | 080h | pop R | 2 | INT,INTG,REAL,BCD,CHAR
9 | 09h | 090h | add R1,R2 | 2 | INT,INTG
10 | 0Ah | 0A0h | add R,M | 2 | INT,INTG
11 | 0Bh | 0B0h | add M,R | 2 | INT,INTG
12 | 0Ch | 0C0h | add R,#d16 | 4 | INT,INTG
13 | 0Dh | 0D0h | adc R1,R2 | 2 | INT,INTG,CHAR
14 | 0Eh | 0E0h | adc R,M | 2 | INT,INTG,CHAR
15 | 0Fh | 0F0h | adc M,R | 2 | INT,INTG,CHAR
16 | 10h | 100h | adc R,#d16 | 4 | INT,INTG,CHAR
17 | 11h | 110h | addf R1,R2 | 2 | REAL
18 | 12h | 120h | addf R,M | 2 | REAL
19 | 13h | 130h | addf M,R | 2 | REAL
20 | 14h | 140h | addf R,#d16 | 4 | REAL
21 | 15h | 150h | addb R1,R2 | 2 | BCD
22 | 16h | 160h | inc R | 2 | INT,INTG,CHAR
23 | 17h | 170h | sub R1,R2 | 2 | INT,INTG
24 | 18h | 180h | sub R,M | 2 | INT,INTG
25 | 19h | 190h | sub M,R | 2 | INT,INTG
26 | 1Ah | 1A0h | sub R,#d16 | 4 | INT,INTG
27 | 1Bh | 1B0h | subc R1,R2 | 2 | INT,INTG,CHAR
28 | 1Ch | 1C0h | subc R,M | 2 | INT,INTG,CHAR
29 | 1Dh | 1D0h | subc M,R | 2 | INT,INTG,CHAR
30 | 1Eh | 1E0h | subc R,#d16 | 4 | INT,INTG,CHAR
31 | 1Fh | 1F0h | subf R1,R2 | 2 | REAL
32 | 20h | 200h | subf R,M | 2 | REAL
33 | 21h | 210h | subf M,R | 2 | REAL
34 | 22h | 220h | subf R,#d16 | 4 | REAL
35 | 23h | 230h | subb R1,R2 | 2 | BCD
36 | 24h | 240h | dec R | 2 | INT,INTG,CHAR
37 | 25h | 250h | neg R | 2 | INT,INTG,CHAR
38 | 26h | 260h | mul R1,R2 | 2 | INT,INTG
39 | 27h | 270h | mul R,M | 2 | INT,INTG
40 | 28h | 280h | mul M,R | 2 | INT,INTG
41 | 29h | 290h | mul R,#d16 | 4 | INT,INTG
42 | 2Ah | 2A0h | mulf R1,R2 | 2 | REAL
43 | 2Bh | 2B0h | mulf R,M | 2 | REAL
44 | 2Ch | 2C0h | mulf M,R | 2 | REAL
45 | 2Dh | 2D0h | mulf R,#d16 | 4 | REAL
46 | 2Eh | 2E0h | div R1,R2 | 2 | INT,INTG
47 | 2Fh | 2F0h | div R,M | 2 | INT,INTG
48 | 30h | 300h | div M,R | 2 | INT,INTG
49 | 31h | 310h | div R,#d16 | 4 | INT,INTG
50 | 32h | 320h | divf R1,R2 | 2 | REAL
51 | 33h | 330h | divf R,M | 2 | REAL
52 | 34h | 340h | divf M,R | 2 | REAL
53 | 35h | 350h | divf R,#d16 | 4 | REAL
54 | 36h | 360h | sqr R | 2 | INT,INTG
55 | 37h | 370h | sqrf R | 2 | REAL
56 | 38h | 380h | pow R1,R2 | 2 | INT,INTG
57 | 39h | 390h | not R | 2 | INT,INTG
58 | 3Ah | 3A0h | and R1,R2 | 2 | INT,INTG,REAL,BCD,CHAR
59 | 3Bh | 3B0h | or R1,R2 | 2 | INT,INTG,REAL,BCD,CHAR
60 | 3Ch | 3C0h | xor R1,R2 | 2 | INT,INTG,REAL,BCD,CHAR
61 | 3Dh | 3D0h | nxor R1,R2 | 2 | INT,INTG,REAL,BCD,CHAR
62 | 3Eh | 3E0h | nand R1,R2 | 2 | INT,INTG,REAL,BCD,CHAR
63 | 3Fh | 3F0h | srl R1,R2 | 2 | INT,INTG,REAL,BCD,CHAR
64 | 40h | 400h | sll R1,R2 | 2 | INT,INTG,REAL,BCD,CHAR
65 | 41h | 410h | sra R1,R2 | 2 | INT,INTG,REAL,BCD,CHAR
66 | 42h | 420h | sla R1,R2 | 2 | INT,INTG,REAL,BCD,CHAR
67 | 43h | 430h | src R1,R2 | 2 | INT,INTG,REAL,BCD,CHAR
68 | 44h | 440h | slc R1,R2 | 2 | INT,INTG,REAL,BCD,CHAR
69 | 45h | 450h | cmp R1,R2 | 2 | INT,INTG,REAL,BCD,CHAR
70 | 46h | 460h | cmp R,M | 2 | INT,INTG,REAL,BCD,CHAR
71 | 47h | 470h | cmp R,#d16 | 4 | INT,INTG,REAL,BCD,CHAR
72 | 48h | 480h | jmp addr | 4
73 | 49h | 490h | ja disp8 | 2
74 | 4Ah | 4A0h | jna disp8 | 2
75 | 4Bh | 4B0h | jc disp8 | 2
76 | 4Ch | 4C0h | jnc disp8 | 2
77 | 4Dh | 4D0h | jz disp8 | 2
78 | 4Eh | 4E0h | jnz disp8 | 2
79 | 4Fh | 4F0h | jo disp8 | 2
80 | 50h | 500h | jno disp8 | 2
81 | 51h | 510h | jp disp8 | 2
82 | 52h | 520h | jnp disp8 | 2
83 | 53h | 530h | js disp8 | 2
84 | 54h | 540h | jns disp8 | 2
85 | 55h | 550h | loop disp8 | 2
86 | 56h | 560h | call addr | 4
87 | 57h | 570h | ret | 2
88 | 58h | 580h | nop | 2
89 | 59h | 590h | hlt | 2
90 | 5Ah | 5A0h | di | 2
91 | 5Bh | 5B0h | ei | 2

# РОЗДІЛ 6. КОМАНДИ ДЛЯ ДЕТАЛЬНОЇ РОЗРОБКИ

Дiлення цілих двійкових чисел зі знаком (співмножники та результат - у доповняльному коді), - цілочисельне ділення: ділене, дільник, частка (зі знаком), остача (без знаку)

accept r10: 0FFFEh

accept r11: 0FFF6h

link l1: ct

\ Oper1 R11

\ Oper2 R10

\ Res R15

\ Usage r2,r3,r4,r7

{ and r2, r11, 8000h; }

{ and r3, r10, 8000h; }

{ xor r2, r2, r3; }

{ or r15, r2, z; }

{ load rn, flags; and nil, r11, 8000h; }

{ cjp rn_z, lp1; }

{ sub r11, z, r11, nz; }

lp1

{ load rn, flags; and nil, r10, 8000h; }

{ cjp rn_z, lp2; }

{ sub r10, z, r10, nz; }

equ x: r11

equ y: r10

lp2

{ load rn, flags; sub nil, x, y, nz; } \ x >= y.

{ cjp not rn_n, div; }

\ x < y

{ xor r3, r3; }

{xor r0,r0;}

{or r0, x;}

{ jmap res; }

div

\ division

{ xor r3, r3; }

dloop

{ load rn, flags; sub x, x, y, nz; }

{ cjp rn_n, res ; }

{ add r3, 1; }

{ jmap dloop; }

res

\ results

{or r0,x;}

{load rn,flags; and nil,x,8000h;}

{cjp rn_z, go;}

{add r0,r10;}

go

{load rn,flags; and nil,r15,8000h;}

{cjp rn_z,respl;}

{sub r15,z,r3,nz;}

respl

{ or r15, r15, r3; }

end{}

Перетворення двійкового коду в двійково-десятковий (для типу даних char)

\ PC R10

\ Addr for stos R11

\ Addr for lods R12

\ Source for stos and getter for lods R13

\ Addr for getter R14

\ Addr for source R15

link l1:ct

link l2:rdm

link ewh:16

accept Rdm_Delay:0

accept r15:30h \ source

dw 30h:13803 \ oper

accept r14:32h \ getter

accept r12:20h \ source lods

accept r11:28h \ getter stos

dw 20h:5,6,7

dw 0:10h \ counter

dw 10h:0,2,0,2,0,2,1 \ steps to lods, stos, conbd

lnext

{xor nil,r0,r0;oey;ewh;} \ read counter

{xor nil,r0,r0;oey;ewl;}

m1{cjp rdm,m1;R;or r0,bus_D,z;}

{or r10,r0,z;}

{xor nil,r0,r0;oey;ewh;} \ read command

{or nil,r0,z;oey;ewl;}

m2{cjp rdm,m2;R;or r0,bus_D,z;}

{or nil,r0,z;oey; cjp zo,fp1;} \ if fprog1 jump

{sub r0,r0,0,z;} \ if fprog2 jump

{cjp zo,fp2;}

{sub r0,r0,0,z;} \ if fprog3 jump

{cjp zo,fp3;}

rets

{xor nil,r0,r0;oey;ewh;} \ Записуємо новий Program Counter

{xor nil,r0,r0;oey;ewl;}

m3{cjp rdm,m3;oey;W;or r10,r10,z;}

{cjp nz,lnext;}

fp1 \ lods

{xor nil,r0,r0;oey;ewh;} \ read oper

{or nil,r12,z;oey;ewl;}

lds1{cjp rdm,lds1;R;or r13,bus_D,z;}

{add r12,r12,z,nz;}

{add r10,z,nz;}

{cjp nz,rets;}

fp2 \ conbd

{xor nil,r0,r0;oey;ewh;} \ read oper

{or nil,r15,z;oey;ewl;}

bd1{cjp rdm,bd1;R;or rq,bus_D,z;}

{and nil,rq,8000h;load rm,flags;}

{cjp rm_z,sd;}

{or r3,r3,00f0h;}

{xor rq,rq,0ffffh;}

{add rq,rq,1;}

sd

{xor r4,r4;}

d1

{add r5,rq,0,z;}

{sub rq,rq,10000,nz;load rm,flags;}

{cjp rm_n,d1done;}

{cjp nz,d1;add r4,r4,nz;}

d1done

{add rq,r5,z;}

{or r3,r3,r4;}

{xor r4,r4;}

{xor r0,r0;}

{or r0,r0,1000h;}

d2

{add r5,rq,0;}

{sub rq,rq,1000,nz;load rm,flags;}

{cjp rm_n,d2done;}

{cjp nz,d2;add r4,r4,r0,z;}

d2done

{add rq,r5,z;}

{xor r0,r0;}

{or r0,r0,0100h;}

d3

{add r5,rq,0,z;}

{sub rq,rq,100,nz;load rm,flags;}

{cjp rm_n,d3done;}

{cjp nz,d3;add r4,r4,r0,z;}

d3done

{add rq,r5,z,z;}

{xor r0,r0;}

{or r0,r0,0010h;}

d4

{add r5,rq,0;}

{sub rq,rq,10,nz;load rm,flags;}

{cjp rm_n,d4done;}

{cjp nz,d4;add r4,r4,r0,z;}

d4done

{add rq,r5,z;}

d5

\{add r5,rq,0;}

{sub rq,rq,1,nz;load rm,flags;}

{cjp rm_n,d5done;}

{cjp nz,d5;add r4,r4,z,nz;}

d5done

{or r2,r2,r4;}

{xor nil,r0,r0;oey;ewh;} \ write r2 and r3 to getter

{or nil,r14,r14;oey;ewl;}

bd2{cjp rdm,bd2;oey;W;or r2,r2,z;}

{add r5,r14,z,nz;}

{xor nil,r0,r0;oey;ewh;}

{or nil,r5,z;oey;ewl;}

bd3{cjp rdm,bd3;oey;W;or r3,r3,z;}

{add r10,r10,z,nz;} \ inc PC

{cjp nz,end;}

fp3 \stos

{xor nil,r0,r0;oey;ewh;}

{or nil,r11,z;oey;ewl;}

sts1{cjp rdm,sts1;oey;W;or r13,r13,z;}

{add r11,r11,z,nz;}

{add r10,z,nz;}

{cjp nz,rets;}

end{}

# СПИСОК ВИКОРИСТАНИХ ДЖЕРЕЛ

1. Проектирование цифровых систем на комплектах микропрограммируемых БИС./Под ред. В.Г.Колесникова.-М.:Радио и связь,1984.-240 с,

2. Микропроцессоры и микропроцессорные комплекты интегральных микросхем: Справ. В 2-х томах./Под ред. В.А.Шахнова.-М.:Радио и связь,1988.

3. Комплект БИС К1804 в процессорах и контроллерах./Под ред. В.Б.Смолова.-М.;Радио и связь,1990.-255 с.

4. Б.А.Калабеков. Микропроцессоры и их применение в системах передачи и обработки сигналов.-М.:Радио и связь, 1988.-368 с.

5. В.И.Корнейчук, В.П.Тарасенко. Вычислительные устройства на микросхемах. Справ. К.Техніка, 1988.-342с.

ІАЛЦ.467400.003 ПЗ 2 Арк Дата Підпис № докум. Арк. Зм

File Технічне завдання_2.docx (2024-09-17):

ТЕХНІЧНЕ ЗАВДАННЯ

1. ПРИЗНАЧЕННЯ ТА ГАЛУЗЬ ЗАСТОСУВАННЯ

Oбчислювальна система з мікропрограмним управлінням розробляється для застосування в інформаційно-керуючих системах, а також може бути використана для наукових та інженерних розрахунків у науково-дослідних організаціях та виробничих об’єднаннях.

2. СКЛАД ОБЧИСЛЮВАЛЬНОЇ СИСТЕМИ

Обчислювальна система на базі мікропроцесорного комплекту K1804 складається із таких основних блоків: процесор, оперативний та постійний запам’ятовувальні пристрої, які утворюють основну пам’ять, а також зовнішні пристрої.

3. ТЕХНІЧНІ ВИМОГИ

3.1. Ємність оперативної пам’яті (ОЗП) – 32 Кбайт.

3.2. Елементна база ОЗП – К541РУ2.

3.3. Ємність постійного запам’ятовувального пристрою (ПЗП) – 16 Кбайти.

3.4. Елементна база ПЗП – К555РЕ4

3.5. Розрядність основної пам’яті (ОЗП і ПЗП) та процесора 32

3.6. Елементна база блоку обробки даних – К1804ВС1

3.7. Наявність схеми прискореного переносу – передбачається

3.8. Елементна база ФАМ – К1804ВУ4

3.9. Елементна база мікропрограмної пам’яті – К541РТ2

3.10. Кількість зовнішніх пристроїв – 16

3.11. Спосіб з’єднання мікросхем К1804ВН1 – послідовний

3.12. Елементна база контролера ПДП – К1804ВУ6

3.13. Обов’язковий тип даних – char

3.14. Команда для детальної розробки – дiлення цілих двійкових чисел зі знаком (співмножники та результат - у доповняльному коді), - цілочисельне ділення: ділене, дільник, частка (зі знаком), остача (без знаку)

3.15. Розробити принципову схему: БПП та БМУ

4. ВИМОГИ ДО НАДІЙНОСТІ.

Напрацювання до відмови – 5000 годин.

Середній термін служби – 5 років.

Час відновлення – 2,5 години.

5. ВИМОГИ ДО КОНСТРУКЦІЇ

Обчислювальна система повинна складатися з набору функціонально та конструктивно завершених блоків, що реалізовані на базі уніфікованих елементів.
| | | | | ІАЛЦ.467400.001 ТЗ
Зм. | Арк | № докум | Підпис | Дата
Розроб. | | Терентьєв І.Д. | | | Обчислювальна система з мікропрограмним управлінням. Технічне завдання | Літ. | | | Арк. | Арк-ів
Перевір. | | Клятченко Я.М. | | | | К | - | - | 1 | 2
| | | | | | КПІ ім. Ігоря Сікорського, ФПМ гр. КВ – 11
Н. контр.
Затв. | | Клятченко Я.М.

6. ПЕРЕЛІК ТЕКСТОВОЇ ТА ГРАФІЧНОЇ ДОКУМЕНТАЦІЇ

ІАЛЦ.467400.000 ОА – Обчислювальна система з мікропрограмним управлінням.

Опис альбому.

ІАЛЦ.467400.001 ТЗ – Обчислювальна система з мікропрограмним управлінням. Технічне завдання.

ІАЛЦ.467400.002 ТП – Обчислювальна система з мікропрограмним управлінням. Відомість технічного проекту.

ІАЛЦ.467400.003 ПЗ – Обчислювальна система з мікропрограмним управлінням. Пояснювальна записка.

ІАЛЦ.467400.004 Е1 – Обчислювальна система з мікропрограмним управлінням. Схема електрична структурна.

ІАЛЦ.467400.005 Е2 – Основна пам’ять. Схема електрична функціональна.

ІАЛЦ.467400.006 E3 – БПП та БМУ. Схема електрична принципова.

ІАЛЦ.467400.007 ПЕ – БПП та БМУ. Перелік елементів.

Аркуш

2

Зм.

Арк.

№ докум.

Підпис

Дата

ІАЛЦ.467400.001 ТЗ

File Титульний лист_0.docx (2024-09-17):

Національний технічний університет України «Київський політехнічний інститут імені Ігоря Сікорського»

ФАКУЛЬТЕТ ПРИКЛАДНОЇ МАТЕМАТИКИ

Кафедра СИСТЕМНОГО ПРОГРАМУВАННЯ І спеціалізованих комп'ютерних систем

КУРСОВИЙ ПРОЄКТ

з дисциплiни "КОМП’ЮТЕРНА СХЕМОТЕХНІКА"

ОБЧИСЛЮВАЛЬНА СИСТЕМА З МІКРОПРОГРАМНИМ УПРАВЛІННЯМ

Керiвник Виконав

Клятченко Я.М. студент 3 курсу

ФПМ, гр. КВ-11

Терентьєв І.Д.

Захищений з оцiнкою

_____________________

"____"______________ 2024 р.

Київ - 2024

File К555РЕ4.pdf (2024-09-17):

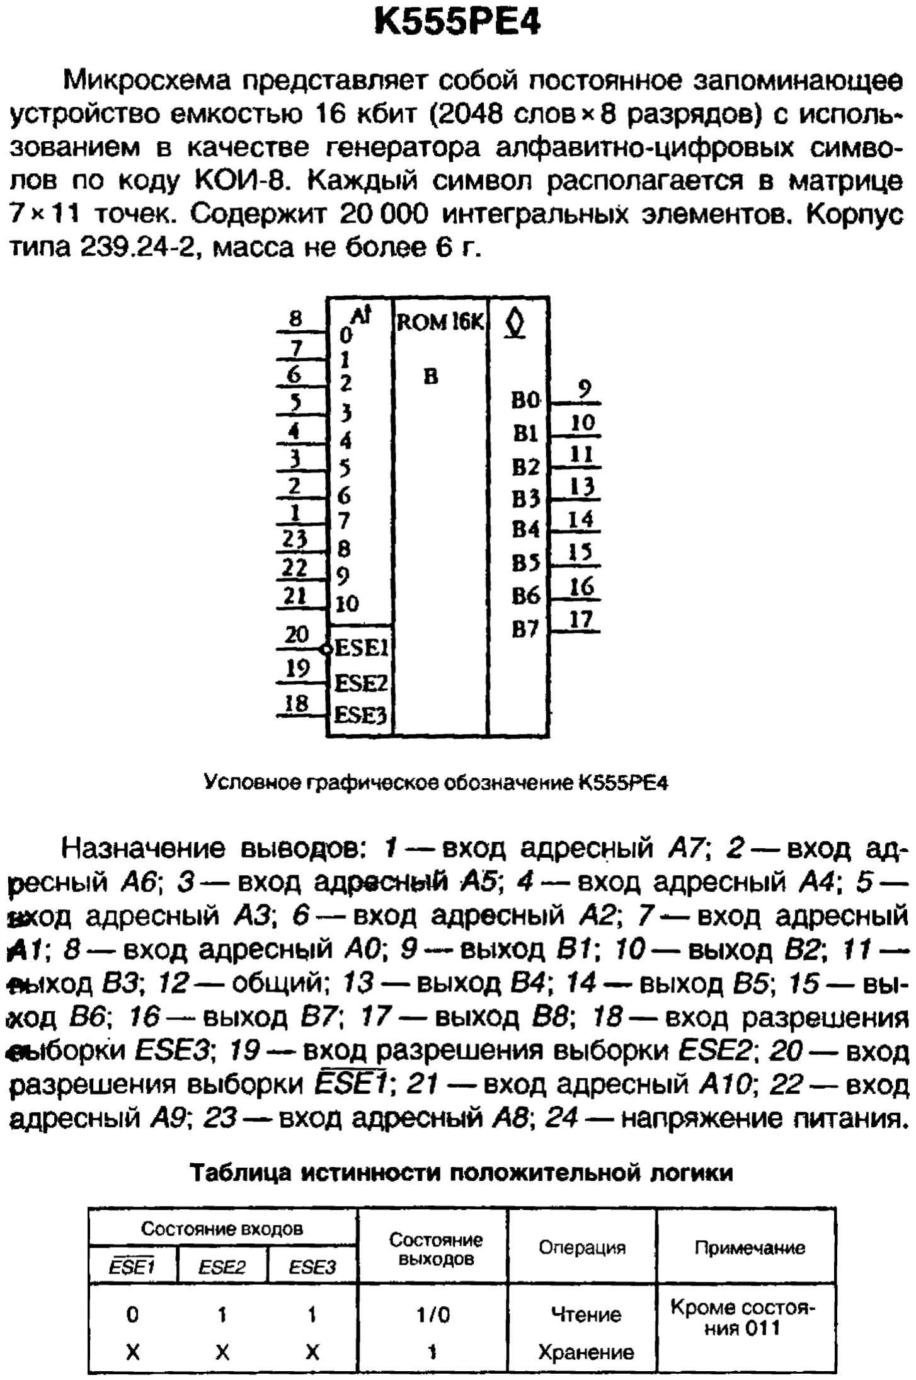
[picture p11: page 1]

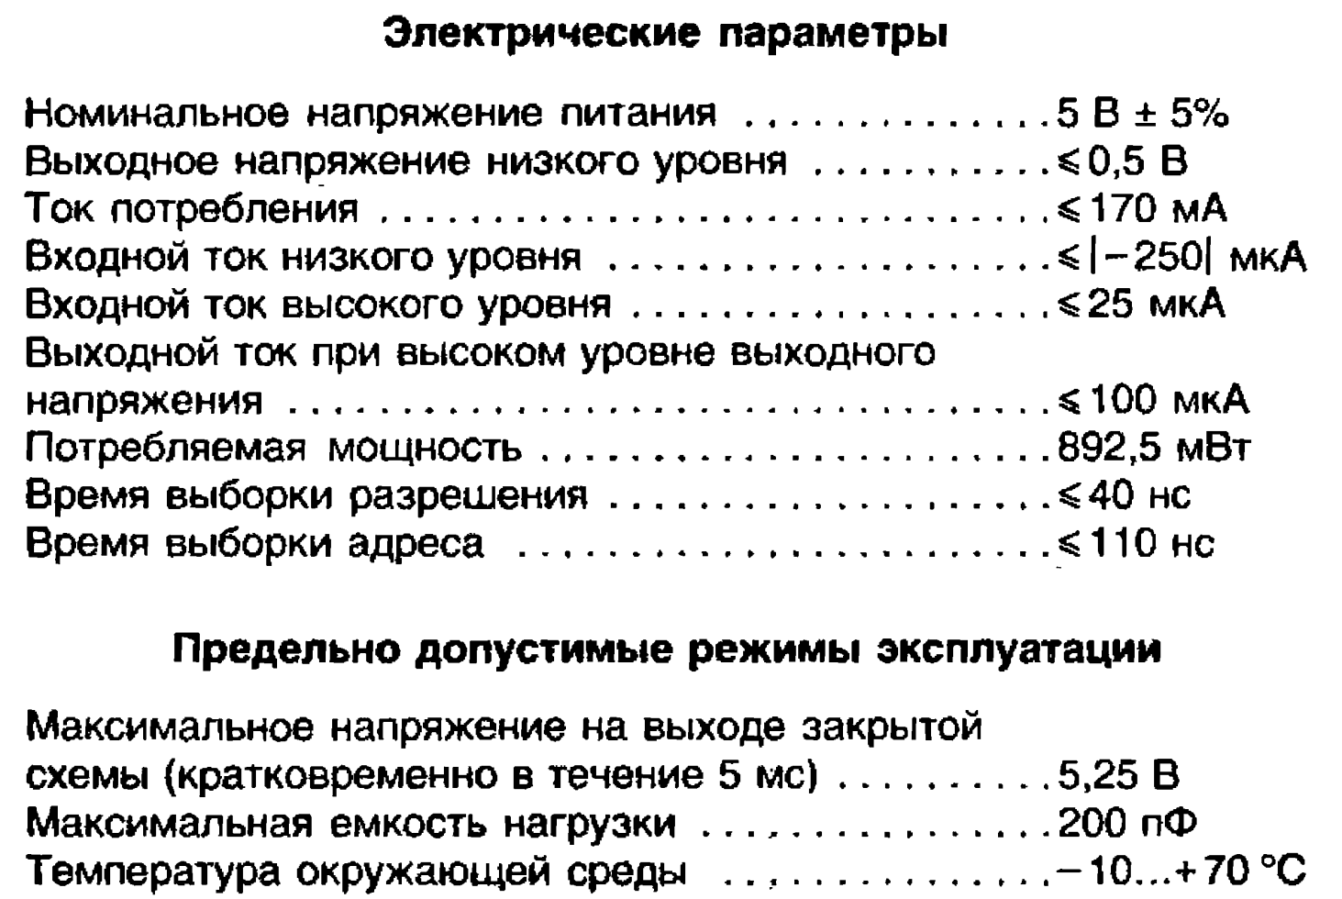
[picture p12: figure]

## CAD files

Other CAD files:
Схема пам'яті_А2.dwg

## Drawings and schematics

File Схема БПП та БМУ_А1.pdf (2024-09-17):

RG

## К580ИР82

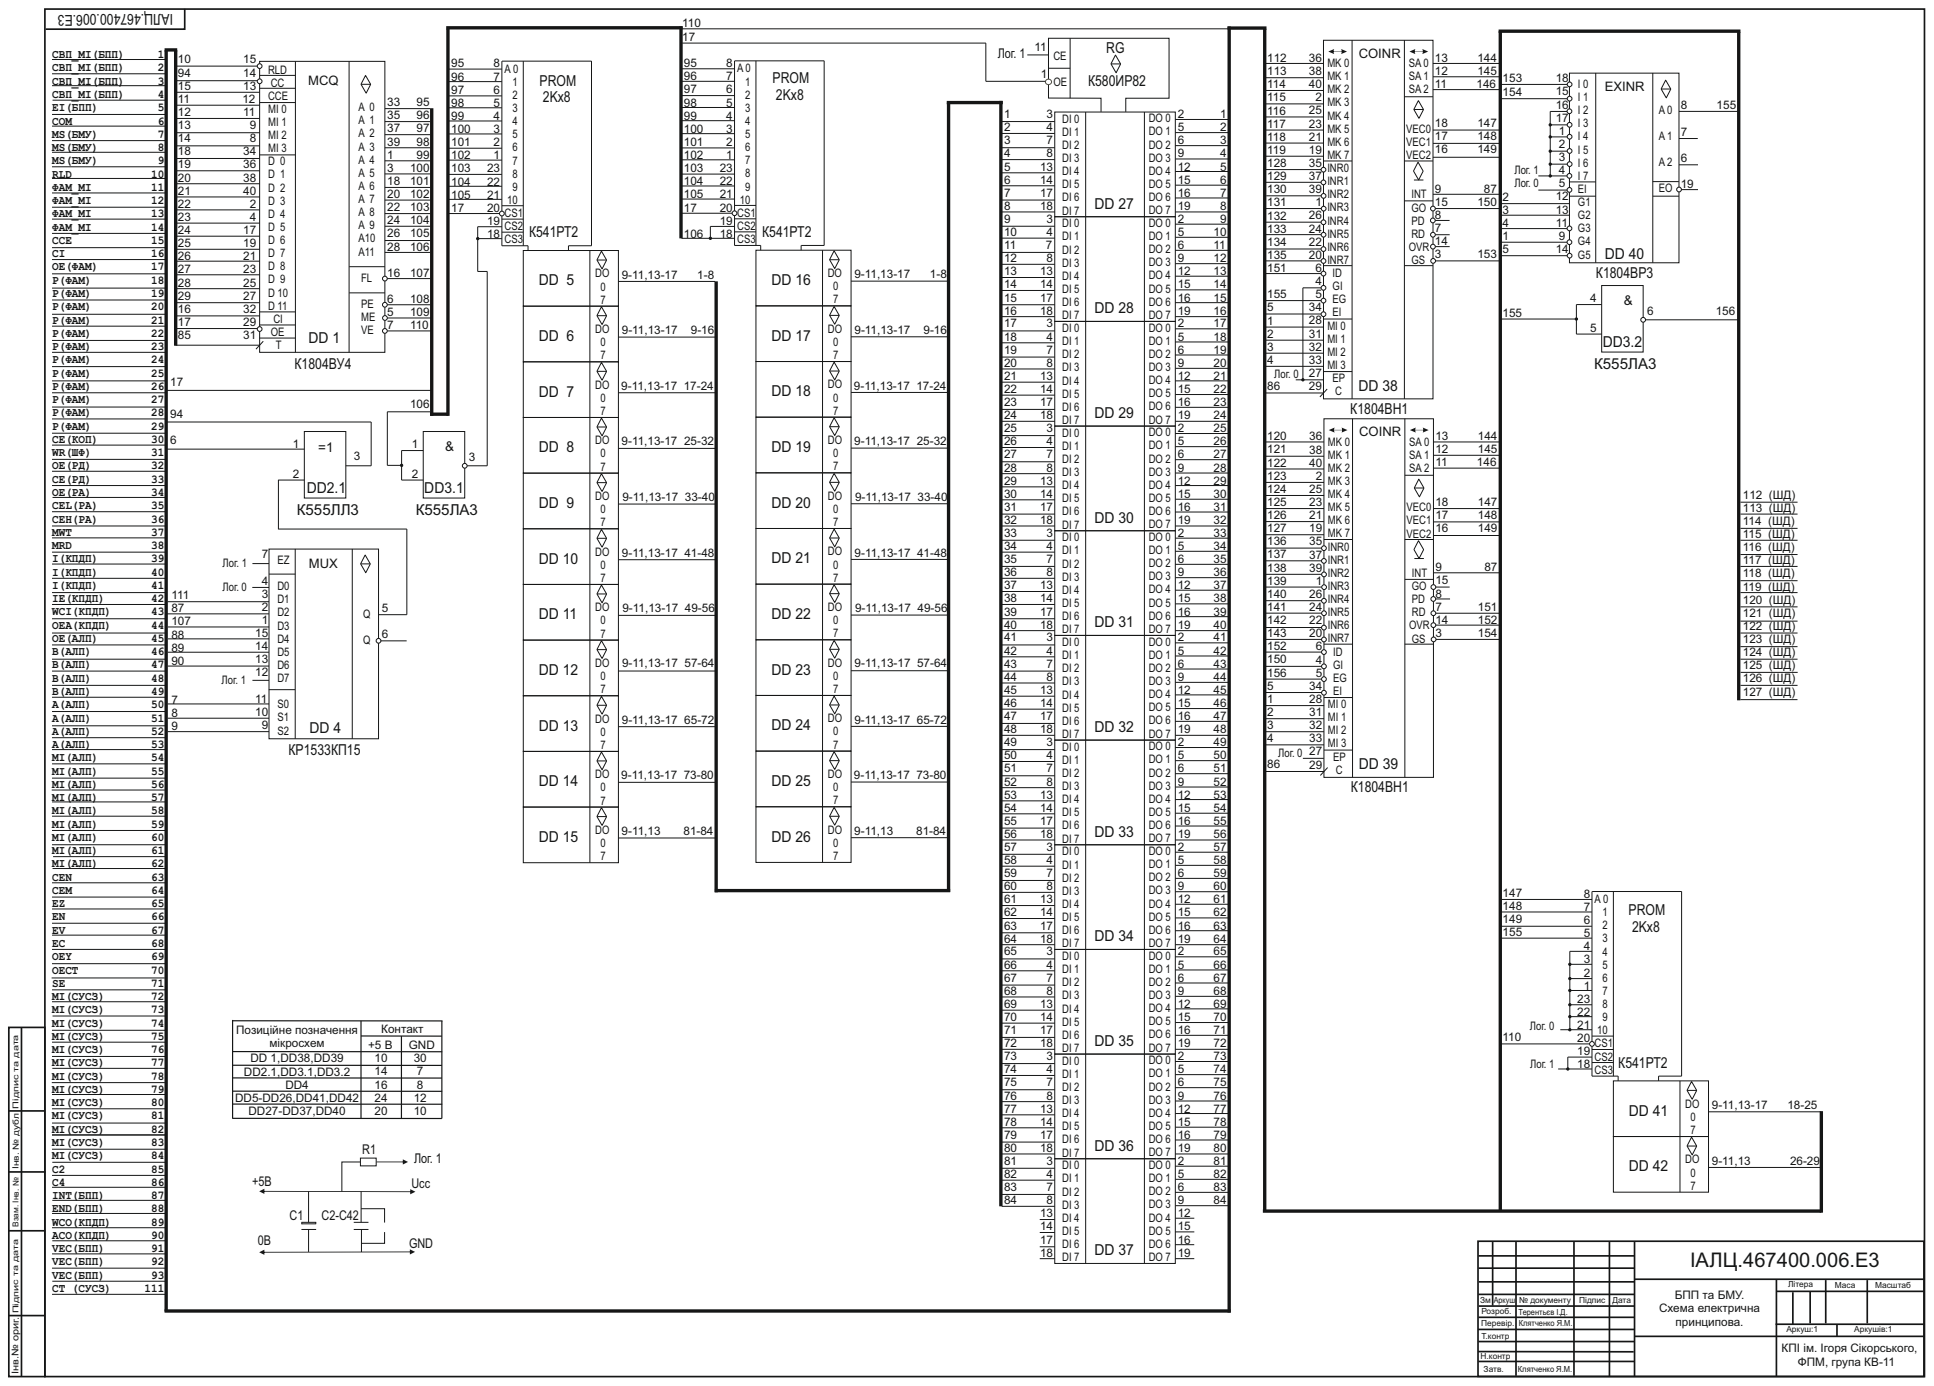
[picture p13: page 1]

DD 1,DD38,DD39 | 10 | 30
DD2.1,DD3.1,DD3.2 | 14 | 7

DD5-DD26,DD41,DD42 | 24 | 12
DD27-DD37,DD40 | 20 | 10

а Взам. Інв. № Інв. № ду

Інв.№ ориг. Підпис та да

Аркуш:1
КПІ ім. Ігоря Сікорського,
ФПМ, група КВ-11

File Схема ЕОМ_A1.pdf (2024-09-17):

## БПП

I

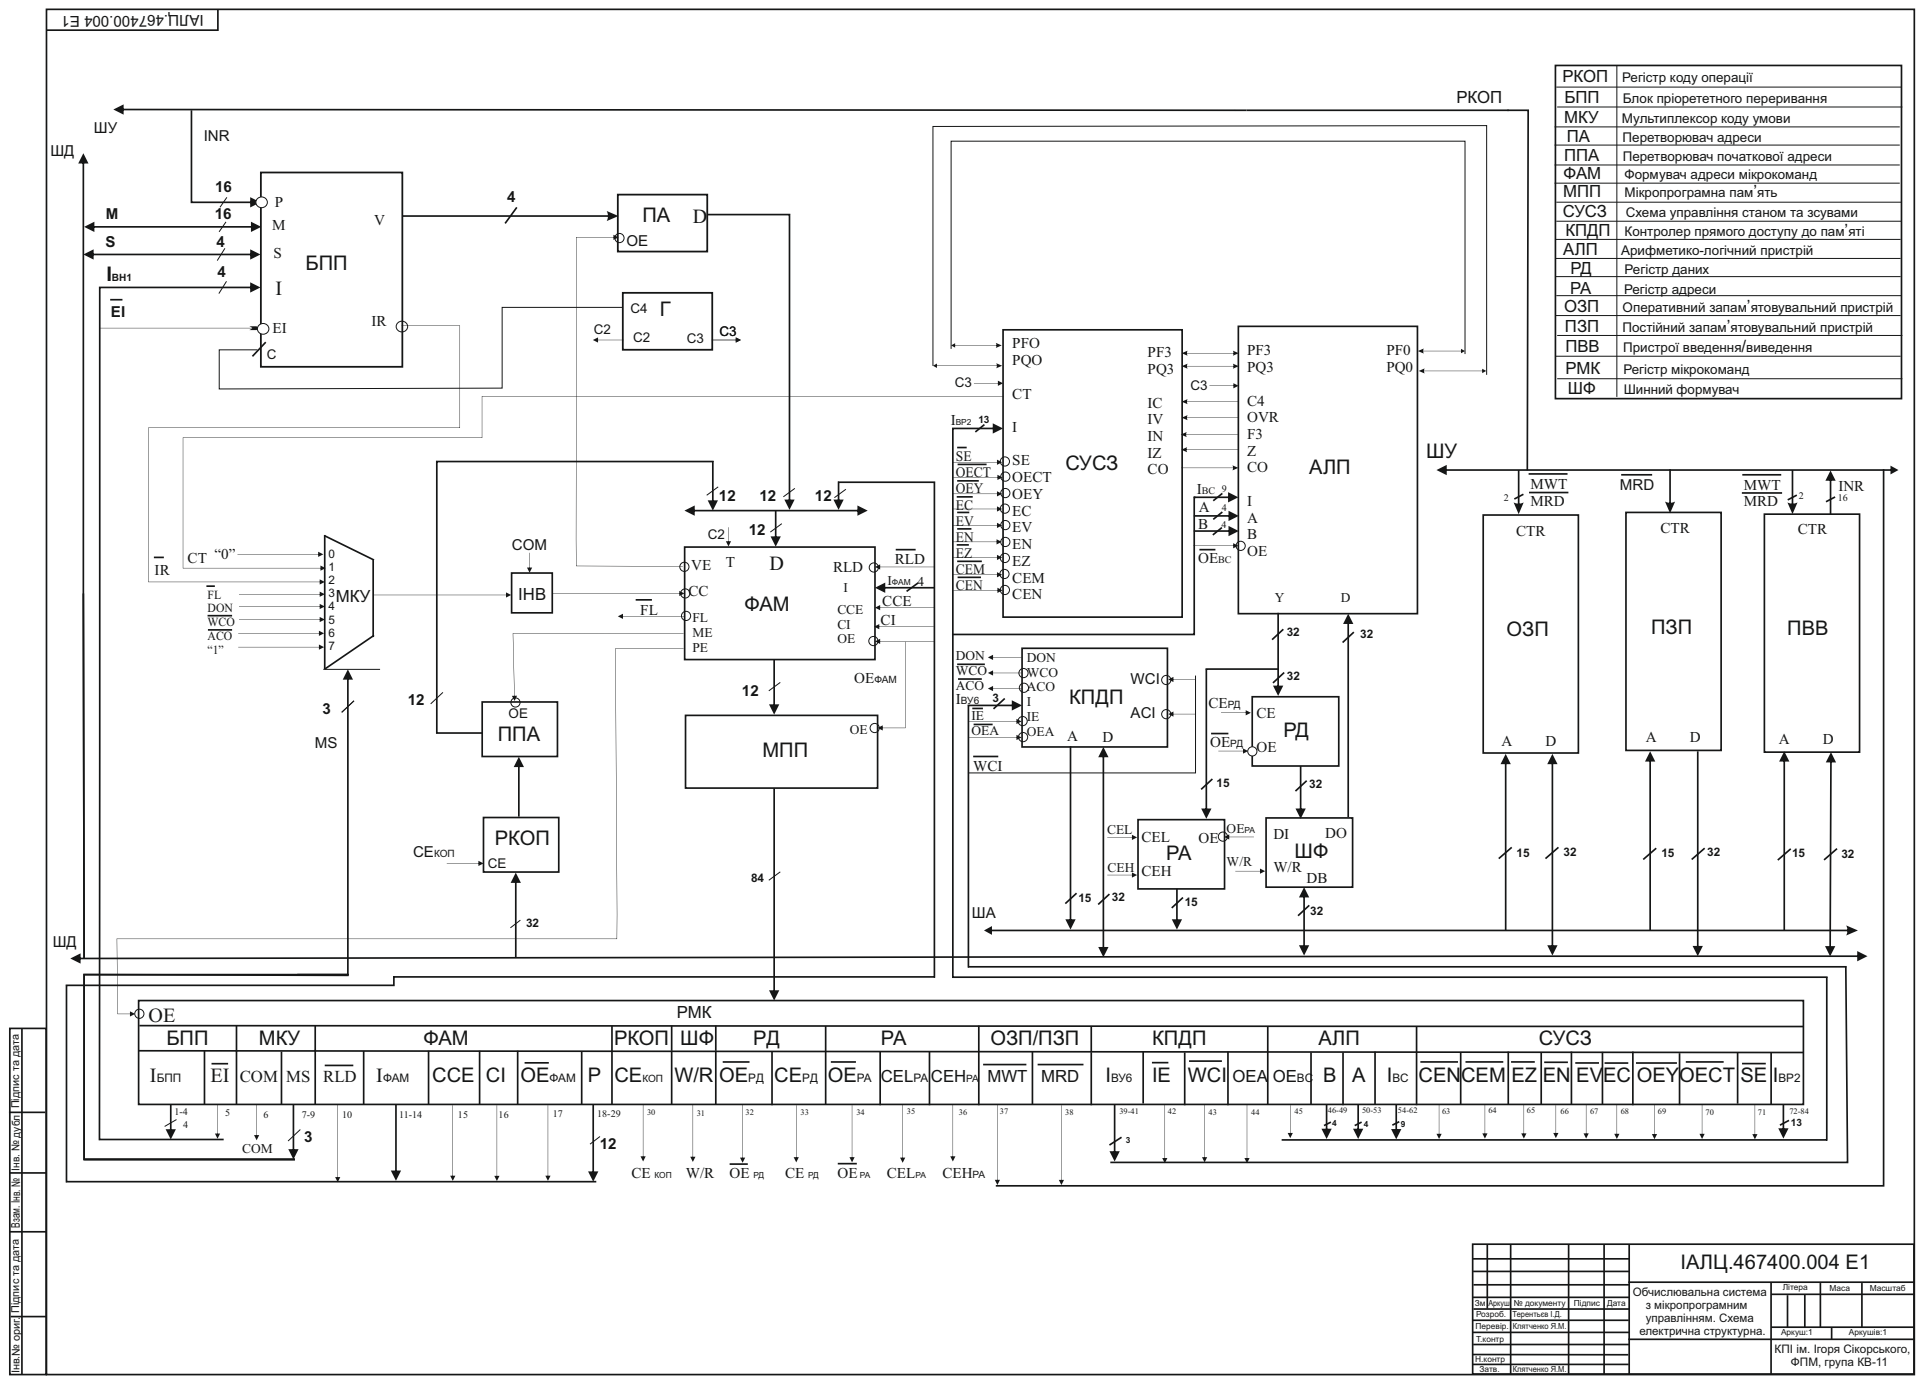
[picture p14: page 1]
ІНВ; ППА; РКОП; ФАМ; RLD; CCE CI OE; МПП; СУСЗ; PFO PQO; SE OECT OEY EC EV EN EZ CEM CEN; АЛП; C4 OVR F3 Z CO; ОЗП; CTR; ПЗП; ПВВ; РМК; БПП; МКУ; ОЗП/ПЗП; КПДП; IБПП; COM; IФАМ; CCE; OEФАМ; CEКОП; W/R OEPД; CEPД; OEPA; CELPA CEHPA; MWT; MRD; IВУ6; WCI OEA OEBC B; IBC; CENCEM EZ EN EVEC OEYOECT SE IBP2; WCI; ACI; DON WCO ACO I IE; OEA; CEL; CEH; INR; IBH1; FL DON WCO ACO “1”; IФАМ 4 CCE CI; IВР2 13; IBC A B; OEBC; MWT MRD; DON WCO ACO IВУ6 IE OEA; CEРД; OEРД; OEРА; CE КОП; CELРА; CEHРА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

л Підпис та да

а Взам. Інв. № Інв. № ду

Інв.№ ориг. Підпис та да

Аркуш:1
КПІ ім. Ігоря Сікорського,
ФПМ, група КВ-11

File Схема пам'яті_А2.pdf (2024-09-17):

# D К555ИД7 RAM СБ1.2 СБ1.3 СБ2.1 СБ2.2 СБ2.3 СБ3 СБ4 СБ5 СБ6 СБ7 СБ8 СБ9 СБ10

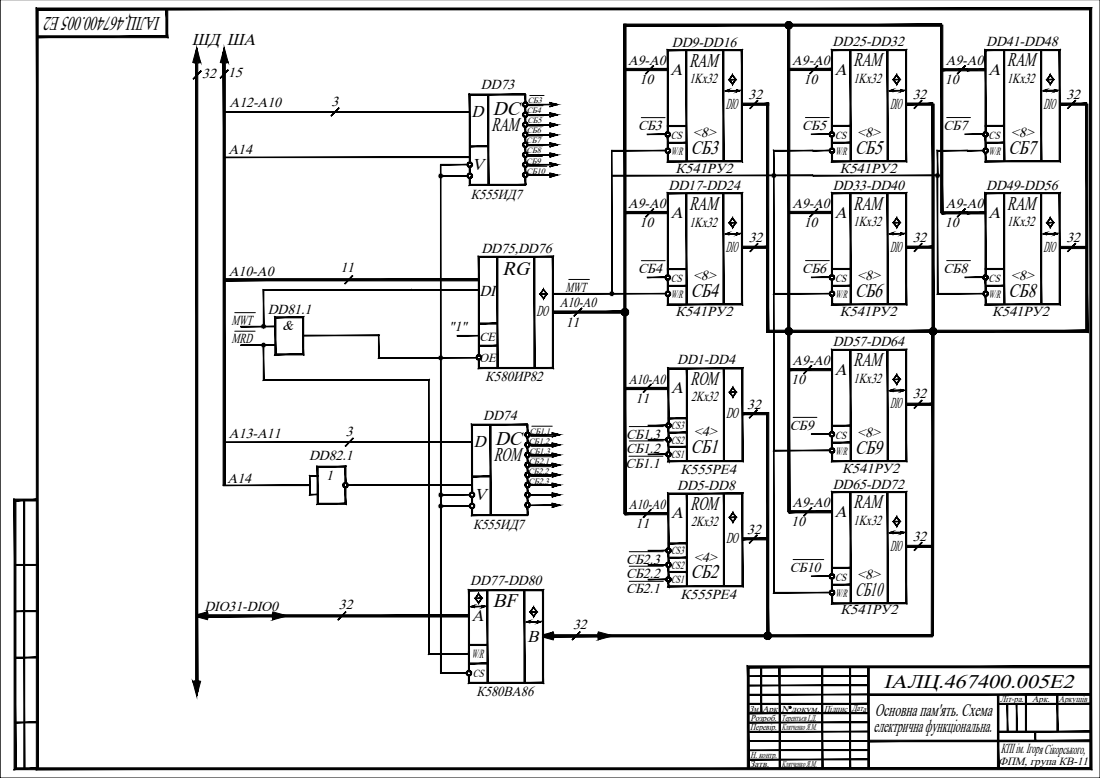
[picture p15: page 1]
Зм. Арк N докум. Пiдпис Дата Розроб. Перевiр. Н. контр. Затв.; Клятченко Я.М. Клятченко Я.М.; Лiт-ра. Арк. Аркушiв ІАЛЦ.467400.005Е2 Основна пам'ять. Схема електрична функцiональна. ІАЛЦ.467400.005 Е2; RAM1Kx32 К541РУ2 W/R A; DIO CS A; DD25-DD32 RGК580ИР82 CEOE DI; DO MWT MRD ШД ША15; 11 A12-A10 DIO31-DIO0; MWT; СБ5 Терентьєв І.Д.; ROM; DO К555РЕ4 2Kx32 ROM 11; КПІ ім. Ігоря Сікорського, ФПМ, група КВ-11 СБ5; DIO DD33-DD40 10; <8> СБ6 RAM1Kx32 К541РУ2 W/R A; DIO DD9-DD16 10; DIO DD17-DD24 10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
